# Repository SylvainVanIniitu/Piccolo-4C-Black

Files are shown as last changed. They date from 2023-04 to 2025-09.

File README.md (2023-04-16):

# PiccoloBlack
MIDI Stochastic Sequencer

Project of a stochastic MIDI sequencer developped since a few years (2016) in solo
I decided in 2023 to make its code and the schematics public and open to modifications by others

Piccolo is a polyrythmic errorist and stochastic MIDI sequencer, slightly verging towards a proto-programmable interpreter, very apt to generative and process-based music.the current version is based on the Teensy 4.1 architecture and MIDI protocol.    The previous versions  were relying on Teensy 3.5 and earlier ATmega2560.   The step to Teensy3.5 had provided 10x more precision in time, and 10x more memory.   the best place to see some movies of the action of the current prototypes is on my fb page : https://www.facebook.com/Piccolo-MIDI-sequencer-230847087794581/ 

i also compiled a few videos here : https://www.youtube.com/watch?v=yQdNbUFVs8c

several records have been released as Sylvain van iniitu or 4LLP4 CH1N0, using Piccolo as its main core

the current software version running the sequencer, and fully written in C, features :

MIDI in
MIDI out
OLED screen ( 4 lines of 20 characters ), in place of LCD screen
tap tempo ( different styles )
4 time-independent layers
64 layer memories ( to store layers and load then when necessary )
Unlimited duration loops ( unless you consider a maximum of 4 years as a limitation.. ), that can be independent.   Precision of 1 msec.  full 16 Channel capacity ( 16 channel can be used on each 4 layers )
Unlimited notes by layer ( up till the time the memory is full… we haven’t got there yet when playing )
more than 100 matrix transformations of the sequences ( delay, variable delay, transposition, harmonization, modulation, tonulation, reverse, inverse, simplification, etc... ) - most of it is crazy stuff, you'll just need to dive in the manual to get a clue
modulation of the layers by sequences : useful for (ir)regular transpositions, by note or by layer, modification of velocity, modification of length of note, etc.
possibility to program regular events, launching a transformation, either in absolute time, or after a certain repetition of one (or several) layers
sending CC to any channel, either time-based ( ex. modifying the length of a reverb every 30 sec ), or by note ( modifying it every 5 notes )
possibility to save and load layers as .txt files on SD cards. you can simply edit those .txt files on any text editor on any platform
reading .MIDI files on the SD card ; possibility to glitch those at core level
USB cable alimentation - does not require a computer to work
non-destructive and non-permanent delays, under various forms : regular delay, quad delay ( adapted from Tambour ), fractal delay ( adapted from Dende )
step sequencer : material 4 steps, but virtual from 2 to 127 steps ; you can program it with any note from any channel

Big thanks to : Ikue Mori, Steve Reich, Two Lone Swordsmen, Christian Wolff, Seth Horvitz (Sutekh), Phillus, Burnt Friedman, Cylob and Actress for most inspiration on building this thing.

Please send me the music you make with this sequencer !

If you make a short run of them, please send me one !

If you want to support, please buy my music at bandcamp E42.A8 : https://e42a8.bandcamp.com 

and if you like it : buy some more at https://stilll-off.bandcamp.com/album/sylvain-van-iniitu-plays-django-reinhardt 

or http://tanukirecords.bandcamp.com/album/vulgar-display-of-debug-vol-3-thrift-thrift-horatio

and yes, invite me for a workshop somewhere, and let me play a concert in your city ! 

P x L x U x R

sylvain van iniitu

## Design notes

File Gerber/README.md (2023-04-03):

BEWARE
there is still one flaw in these gerber files :
you'll need to attach a jumpwire from (-) to the mass in the PCB
please use the kiCad files named 14juillet to generate new Gerber files
i'll update ASAP

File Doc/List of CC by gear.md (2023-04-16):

COLECTED LIST of CC commands for useful gear ; please feel free to add some

// TX81Z

// Nord Drum 2

// Micro Sampler KORG

// Nord Lead 2

// Electribe mk2 

// Sherman

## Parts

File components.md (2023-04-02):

i will keep here a simple list of the components for the project, and a quick link on where to buy them
i mostly used Reichelt.de and Mouser.com until now, but i'll let it open for anyone who wants to contribute
i still need to indicated how many of each you'll need... 

let's start, with the obvious : 
* Teensy 4.1          https://www.pjrc.com/store/teensy41.html 
i used the normal version, but the NE should do fine as well

* Pushbuttons : Keylock Switches PB SWITCH SPST 
https://www.mouser.be/ProductDetail/CK/KS11R23CQD 
https://www.mouser.be/ProductDetail/CK/KS11R21CQD 
https://www.mouser.be/ProductDetail/CK/KS11R22CQD 

* DMX in : XLR connector
https://www.mouser.be/ProductDetail/Neutrik/NC3FBH2 

* MIDI connectors :
https://www.reichelt.de/be/en/din-socket-5-pin-semi-circular-printed-version-mabp-5s-p11178.html 

* Rectifier diode
https://www.reichelt.de/be/en/rectifier-diode-do35-100-v-0-2-a-1n-914-p1763.html 

* 6N138 optocoupler : necessary for MIDI in
https://www.reichelt.de/be/en/optocoupler-6n-138-p2859.html 

* MAX 485 CPA RS485/422 transceiver, DIP-8 
https://www.reichelt.de/be/en/rs485-422-transceiver-dip-8-max-485-cpa-p39599.html

* Rotary encoder with pushbutton 
https://www.reichelt.de/be/en/alps-stec12e-rotary-pulse-encoder-24-24-vert-w-pb-stec12e08-p73923.html 
* idem without pushbutton 
https://www.reichelt.de/be/en/alps-stec12e-rotary-pulse-encoder-24-24-vert-w-o-pb-stec12e07-p73922.html 

* OLED Screen : 
 /www.nhdforum.newhavendisplay.com/index.php?topic=914.0
https://www.mouser.be/ProductDetail/Newhaven-Display/NHD-0420CW-AY3 
i wrote a detailed post on wiring this one, here : 
https://forum.pjrc.com/threads/65710-teensy-4-1-OLED-4x20-NHD-0420CW-AY3 

* stuff to mount the whole ( legs, spacers, screws, etc )
https://www.reichelt.de/be/en/spacers-metal-6-edge-m4-5-mm-vt-da4-5mm-p231472.html 
https://www.reichelt.de/be/en/spacers-metal-6-edge-m3-5-mm-vt-da-5mm-p231465.html

* slider ( developpment not completely finished on this, though ) 
https://www.reichelt.de/be/en/alps-high-quality-sliding-potentiometer-linear-stereo-10k-rs60n12-lin10k-p73870.html  
+ fader button 
https://www.reichelt.de/be/en/fader-knob-for-rs60112-bl-knopf-4x1-2sw-p73945.html

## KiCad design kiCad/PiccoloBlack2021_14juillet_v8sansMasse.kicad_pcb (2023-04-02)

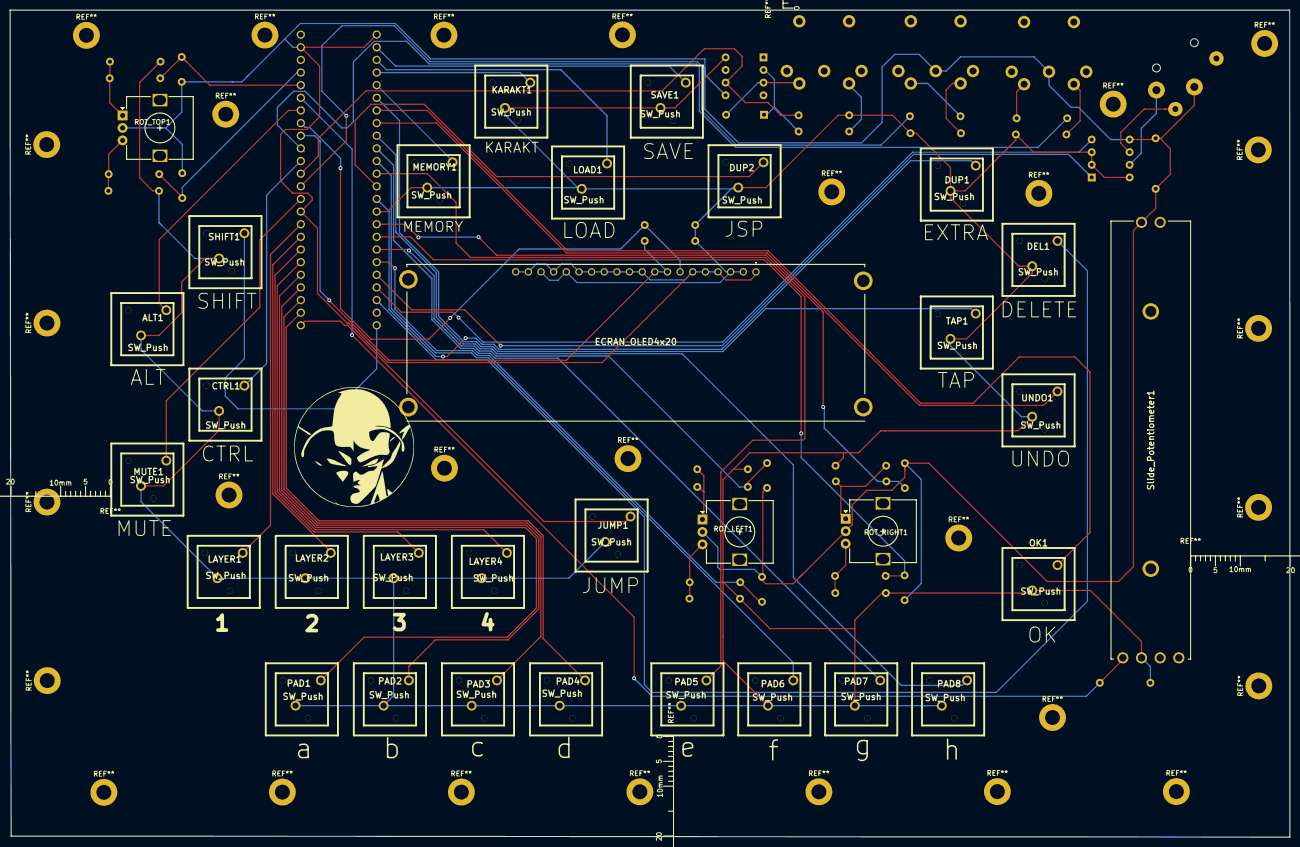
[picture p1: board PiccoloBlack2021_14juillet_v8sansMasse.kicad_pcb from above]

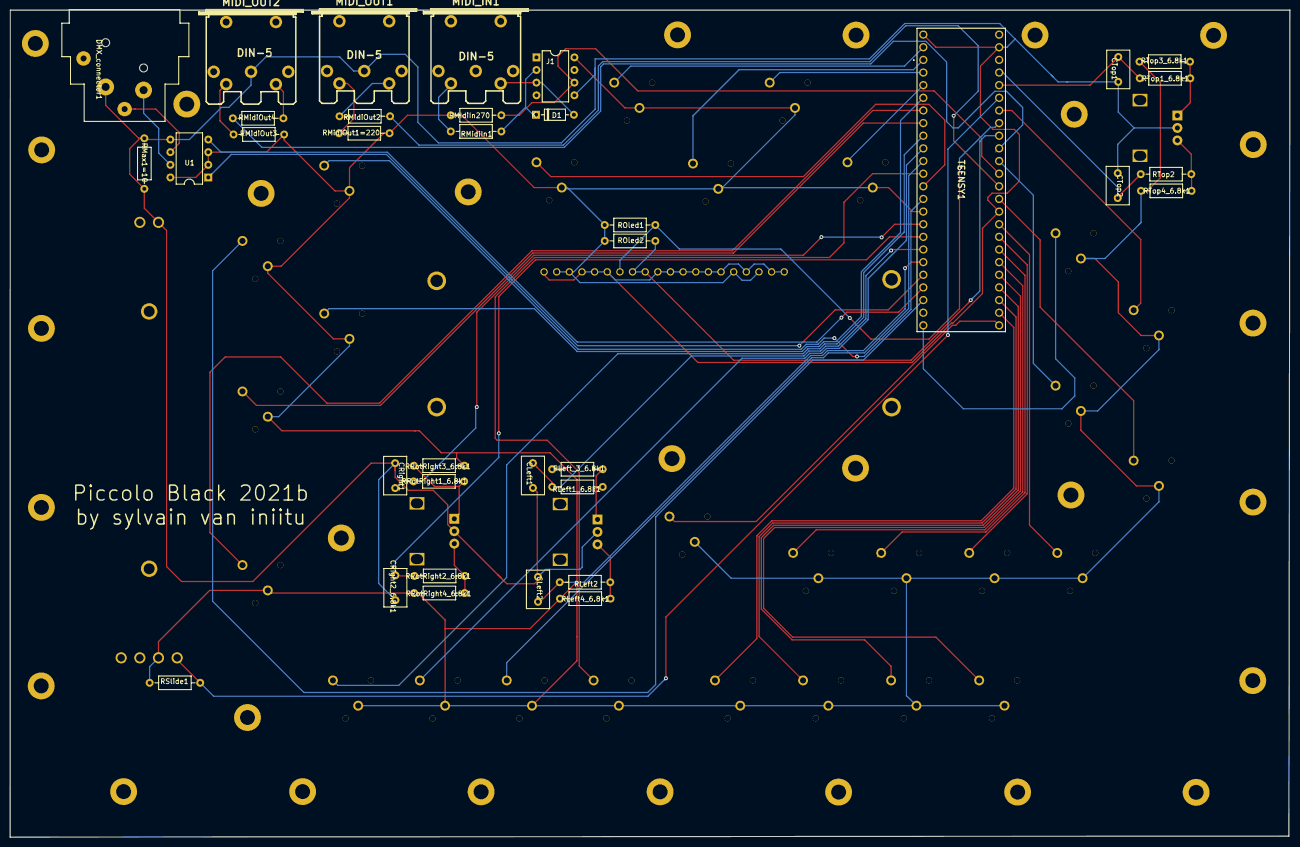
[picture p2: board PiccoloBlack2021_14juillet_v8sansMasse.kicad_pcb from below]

Board: 2 copper layers, 257.1 x 166.2 mm, 68 parts (36 on the bottom side), 58 nets.

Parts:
ALT1: SW_Push; PCB_PUSH2
CLeft1, CLeft2: C 0.01u = 103; C_Disc_D7.5mm_W4.4mm_P5.00mm
CRight1, CRight2_6.8k1: C 0.01u = 103; C_Disc_D7.5mm_W4.4mm_P5.00mm
CTRL1: SW_Push; PCB_PUSH2
CTop1, CTop2: C 0.01u = 103; C_Disc_D7.5mm_W4.4mm_P5.00mm
D1: 1N914; D_DO-35_SOD27_P7.62mm_Horizontal
DEL1: SW_Push; PCB_PUSH2
DMX_connector1: NC3FBH2; Jack_XLR_Neutrik_NC3FBH2_Horizontal
DUP1, DUP2: SW_Push; PCB_PUSH2
ECRAN_OLED4x20: NHD-0420CW-AW3; NHD0420CWAW3
J1: Conn_02x04_Counter_Clockwise; DIP-8_W7.62mm
JUMP1: SW_Push; PCB_PUSH2
KARAKT1: SW_Push; PCB_PUSH2
LAYER1, LAYER2, LAYER3, LAYER4: SW_Push; PCB_PUSH2
LOAD1: SW_Push; PCB_PUSH2
MEMORY1: SW_Push; PCB_PUSH2
MIDI_IN1: DIN-5; din-5
MIDI_OUT1, MIDI_OUT2: DIN-5; din-5
MUTE1: SW_Push; PCB_PUSH2
OK1: SW_Push; PCB_PUSH2
PAD1, PAD2, PAD3, PAD4, PAD5, PAD6, PAD7, PAD8: SW_Push; PCB_PUSH2
RLeft1_6.8k1, RLeft2, RLeft4_6.8k1: _6.8k; R_Axial_DIN0207_L6.3mm_D2.5mm_P10.16mm_Horizontal
RLeft_3_6.8k1: _6.8k; R_Axial_DIN0207_L6.3mm_D2.5mm_P10.16mm_Horizontal
RMIdiIn270: 270; R_Axial_DIN0207_L6.3mm_D2.5mm_P10.16mm_Horizontal
RMax1=10: R 10; R_Axial_DIN0207_L6.3mm_D2.5mm_P10.16mm_Horizontal
RMidiIn1: 220; R_Axial_DIN0207_L6.3mm_D2.5mm_P10.16mm_Horizontal
RMidiOut1=220, RMidiOut2, RMidiOut3, RMidiOut4: 220; R_Axial_DIN0207_L6.3mm_D2.5mm_P10.16mm_Horizontal
ROT_LEFT1: Rotary_Encoder; RotaryEncoder_Alps_EC12E_Vertical_H20mm
ROT_RIGHT1: Rotary_Encoder; RotaryEncoder_Alps_EC12E_Vertical_H20mm
ROT_TOP1: Rotary_Encoder; RotaryEncoder_Alps_EC12E_Vertical_H20mm
ROled1, ROled2: 6,8k; R_Axial_DIN0207_L6.3mm_D2.5mm_P10.16mm_Horizontal
RRotRight1_6.8k1: 6.8k; R_Axial_DIN0207_L6.3mm_D2.5mm_P10.16mm_Horizontal
RRotRight2_6.8k1, RRotRight3_6.8k1, RRotRight4_6.8k1: _6.8k; R_Axial_DIN0207_L6.3mm_D2.5mm_P10.16mm_Horizontal
RSlide1: 3,3k; R_Axial_DIN0207_L6.3mm_D2.5mm_P10.16mm_Horizontal
RTop1_6.8k1, RTop2, RTop3_6.8k1, RTop4_6.8k1: _6.8k; R_Axial_DIN0207_L6.3mm_D2.5mm_P10.16mm_Horizontal
SAVE1: SW_Push; PCB_PUSH2
SHIFT1: SW_Push; PCB_PUSH2
Slide_Potentiometer1: RS60N1219A04
TAP1: SW_Push; PCB_PUSH2
TEENSY1: TEENSY_4.1; TEENSY41sans_trous_du_milieux
U1: MAX485E; DIP-8_W7.62mm
UNDO1: SW_Push; PCB_PUSH2

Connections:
GND: CLeft1.1, CLeft2.1, CRight1.1, CRight2_6.8k1.1, CTop1.1, CTop2.1, DMX_connector1.1, ECRAN_OLED4x20.1, ECRAN_OLED4x20.4, ECRAN_OLED4x20.5, ECRAN_OLED4x20.6, ECRAN_OLED4x20.10, ECRAN_OLED4x20.11, ECRAN_OLED4x20.12, ECRAN_OLED4x20.13, ECRAN_OLED4x20.14, ECRAN_OLED4x20.15, ECRAN_OLED4x20.17, ECRAN_OLED4x20.19, ECRAN_OLED4x20.20, J1.5, MIDI_OUT1.2, MIDI_OUT2.2, RMax1=10.1, RMax1=10.2, ROT_LEFT1.C, ROT_RIGHT1.C, ROT_TOP1.C, Slide_Potentiometer1.5, TEENSY1.G1, TEENSY1.G2, TEENSY1.G3, U1.5
unnamed: ALT1.1, TEENSY1.20
unnamed: ALT1.2, CTRL1.2, DEL1.2, DUP1.2, DUP2.2, ECRAN_OLED4x20.2, ECRAN_OLED4x20.3, ECRAN_OLED4x20.16, ECRAN_OLED4x20.18, J1.8, JUMP1.2, KARAKT1.2, LAYER1.2, LAYER2.2, LAYER3.2, LAYER4.2, LOAD1.2, MEMORY1.2, MUTE1.2, OK1.2, PAD1.2, PAD2.2, PAD3.2, PAD4.2, PAD5.2, PAD6.2, PAD7.2, PAD8.2, RLeft4_6.8k1.2, RLeft_3_6.8k1.1, RMIdiIn270.2, RMidiOut1=220.1, RMidiOut3.1, ROled1.1, ROled2.2, RRotRight3_6.8k1.1, RRotRight4_6.8k1.2, RSlide1.1, RTop3_6.8k1.1, RTop4_6.8k1.2, SAVE1.2, SHIFT1.2, Slide_Potentiometer1.1, TAP1.2, TEENSY1.42, U1.2, U1.3, U1.8, UNDO1.2
unnamed: CLeft1.2, RLeft1_6.8k1.2, TEENSY1.26
unnamed: CLeft2.2, RLeft2.2, TEENSY1.27
unnamed: CRight1.2, RRotRight1_6.8k1.2, TEENSY1.24
unnamed: CRight2_6.8k1.2, RRotRight2_6.8k1.2, TEENSY1.25
unnamed: CTRL1.1, TEENSY1.16
unnamed: CTop1.2, RTop1_6.8k1.2, TEENSY1.22
unnamed: CTop2.2, RTop2.2, TEENSY1.23
unnamed: D1.1, J1.2, RMidiIn1.1
unnamed: D1.2, J1.3, MIDI_IN1.5
unnamed: DEL1.1, TEENSY1.30
unnamed: DMX_connector1.2, U1.7
unnamed: DMX_connector1.3, U1.6
unnamed: DUP1.1, TEENSY1.12
unnamed: DUP2.1, TEENSY1.11
unnamed: ECRAN_OLED4x20.7, ROled1.2, TEENSY1.19
unnamed: ECRAN_OLED4x20.8, ECRAN_OLED4x20.9, ROled2.1, TEENSY1.18
unnamed: J1.6, RMIdiIn270.1, TEENSY1.15
unnamed: JUMP1.1, TEENSY1.33
unnamed: KARAKT1.1, TEENSY1.2
unnamed: LAYER1.1, TEENSY1.41
unnamed: LAYER2.1, TEENSY1.40
unnamed: LAYER3.1, TEENSY1.39
unnamed: LAYER4.1, TEENSY1.38
unnamed: LOAD1.1, TEENSY1.1
unnamed: MEMORY1.1, TEENSY1.3
unnamed: MIDI_IN1.4, RMidiIn1.2
unnamed: MIDI_OUT1.4, RMidiOut1=220.2
unnamed: MIDI_OUT1.5, RMidiOut2.2
unnamed: MIDI_OUT2.4, RMidiOut3.2
unnamed: MIDI_OUT2.5, RMidiOut4.2
unnamed: MUTE1.1, TEENSY1.13
unnamed: OK1.1, TEENSY1.5
unnamed: PAD1.1, TEENSY1.37
unnamed: PAD2.1, TEENSY1.36
unnamed: PAD3.1, TEENSY1.35
unnamed: PAD4.1, TEENSY1.34
unnamed: PAD5.1, TEENSY1.10
unnamed: PAD6.1, TEENSY1.9
unnamed: PAD7.1, TEENSY1.8
unnamed: PAD8.1, TEENSY1.7
unnamed: RLeft1_6.8k1.1, RLeft_3_6.8k1.2, ROT_LEFT1.A
unnamed: RLeft2.1, RLeft4_6.8k1.1, ROT_LEFT1.B
unnamed: RMidiOut2.1, TEENSY1.14
unnamed: RMidiOut4.1, TEENSY1.17
unnamed: ROT_RIGHT1.A, RRotRight1_6.8k1.1, RRotRight3_6.8k1.2
unnamed: ROT_RIGHT1.B, RRotRight2_6.8k1.1, RRotRight4_6.8k1.1
unnamed: ROT_TOP1.A, RTop1_6.8k1.1, RTop3_6.8k1.2
unnamed: ROT_TOP1.B, RTop2.1, RTop4_6.8k1.1
unnamed: RSlide1.2, Slide_Potentiometer1.3, TEENSY1.21
unnamed: SAVE1.1, TEENSY1.57
unnamed: SHIFT1.1, TEENSY1.32
unnamed: TAP1.1, TEENSY1.4
unnamed: TEENSY1.6, UNDO1.1
unnamed: TEENSY1.28, U1.1
unnamed: TEENSY1.29, U1.4

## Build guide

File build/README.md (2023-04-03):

this folder contains one .HEX file that works as one of the latest tested software
you can upload this directly to Piccolo using the Teensy loader if you dont want to compile all the files yourself

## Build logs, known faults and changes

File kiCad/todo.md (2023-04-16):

missing prints on the schematics for 
* OLED-0420CW-AW3
* TEENSY_4.1
* DMX NC3FBH2 

refaire un plan avec Zone de Masse

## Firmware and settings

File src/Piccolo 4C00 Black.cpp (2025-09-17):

/*

here

PPPPPPPPPPPPPPPPP     iiii                                                           lllllll                              444444444
P::::::::::::::::P   i::::i                                                          l:::::l                             4::::::::4
P::::::PPPPPP:::::P   iiii                                                           l:::::l                            4:::::::::4
PP:::::P     P:::::P                                                                 l:::::l                           4::::44::::4
  P::::P     P:::::Piiiiiii     cccccccccccccccc    cccccccccccccccc   ooooooooooo    l::::l    ooooooooooo           4::::4 4::::4      cccccccccccccccc
  P::::P     P:::::Pi:::::i   cc:::::::::::::::c  cc:::::::::::::::c oo:::::::::::oo  l::::l  oo:::::::::::oo        4::::4  4::::4    cc:::::::::::::::c
  P::::PPPPPP:::::P  i::::i  c:::::::::::::::::c c:::::::::::::::::co:::::::::::::::o l::::l o:::::::::::::::o      4::::4   4::::4   c:::::::::::::::::c
  P:::::::::::::PP   i::::i c:::::::cccccc:::::cc:::::::cccccc:::::co:::::ooooo:::::o l::::l o:::::ooooo:::::o     4::::444444::::444c:::::::cccccc:::::c
  P::::PPPPPPPPP     i::::i c::::::c     cccccccc::::::c     ccccccco::::o     o::::o l::::l o::::o     o::::o     4::::::::::::::::4c::::::c     ccccccc
  P::::P             i::::i c:::::c             c:::::c             o::::o     o::::o l::::l o::::o     o::::o     4444444444:::::444c:::::c
  P::::P             i::::i c:::::c             c:::::c             o::::o     o::::o l::::l o::::o     o::::o               4::::4  c:::::c
  P::::P             i::::i c::::::c     cccccccc::::::c     ccccccco::::o     o::::o l::::l o::::o     o::::o               4::::4  c::::::c     ccccccc
PP::::::PP          i::::::ic:::::::cccccc:::::cc:::::::cccccc:::::co:::::ooooo:::::ol::::::lo:::::ooooo:::::o               4::::4  c:::::::cccccc:::::c
P::::::::P          i::::::i c:::::::::::::::::c c:::::::::::::::::co:::::::::::::::ol::::::lo:::::::::::::::o             44::::::44 c:::::::::::::::::c
P::::::::P          i::::::i  cc:::::::::::::::c  cc:::::::::::::::c oo:::::::::::oo l::::::l oo:::::::::::oo              4::::::::4  cc:::::::::::::::c
PPPPPPPPPP          iiiiiiii    cccccccccccccccc    cccccccccccccccc   ooooooooooo   llllllll   ooooooooooo                4444444444    cccccccccccccccc

2016-2025 sylvain van iniitu - some rights reserved -
This program is free software; you can redistribute it and/or
modify it under the terms of the Creative Commons 4.0 CC BY-NC-SA Licence

www.iniitu.net
you can support my music on Bandcamp > https://e42a8.bandcamp.com 
if you would like to buy a PCB get in touch

*/

// TODO

// avant Version RESIDENZ
// J'ai sacrifié GetNameTest pour Comb2 ! il faut restaurer ça pour Teensy !

// version qui effectue un pas en arrière concernant le CCMod
// alors que j'avais développé une version avec pointeurs, je retourne ici vers un array

// la valeur réelle est affichée en softwareValueEncoderRight
// celle ci est transmise à la transformation
// pour le random de Event, il faudra prévoir qu'il balance entre min et max de la transformation prévue
// vérifier l'affichage de ligne2 dans trasnformation 134 : choix de valeur min et valeur max de Event Transfo

// QUAND NOUVELLE VARIABLE INFLUENCANT LE JEU ET DEVANT ETRE SAUVEE SOUS KARAKT
// AJOUTER AU SAVE
// AJOUTER AU LOAD ( à partir de la ligne précédent )
// AJOUTER AU SAVE TO MEM
// AJOUTE AU LOAD FROM MEM

// 1 -
//  aller dans saveCurrentandMemKarakt() dans SaveLoadLocal.h
//  on rajoute en bas de cette fonction des _printToKarakt avec des chiffres consécutifs, ainsi que le nom de variable et description
//  faire un compile pour vérifier que OK

// 2
//  un peu plus bas, dans le même fichier, même fonction recopier les nouvelles lignes et modifier en fromKMem_int_printToKarakt
//  re-compiler

// 3
//  aller dans la fonction loadLocal2, même fichier
//  ajouters les nouvelles lignes et modifier en    int_loadFromKarakt(128, &keepStepzBUG );
//  re-compiler

// 5
//  recopier ces mêmes lignes EXACTEMENT sans rien modifer dans la fonction loadKarakt_from_KMem
//  re-compiler

// 4
//  aller ensuite dans le fichier karaktPile.h
//  trouver la fonction saveKarakt_to_KMem
//  y recopier les mêmes lignes juste modifée et en changeant le début par econome_int_saveToKMem(place,
//  sans le &
//  re-compiler

// procédures standard

#include <Arduino.h>
#include <MIDI.h>
#include <Encoder.h>
#include <EEPROM.h>
#include <bounce.h>
#include <affichage_functions.h>
#include <TeensyDMX.h>

// BLACK05 tentative de réinstauration de microSD en s'inspirant de
// https://forum.pjrc.com/threads/66326-Interference-between-SDFat-SDIO-and-I2S-on-T4-1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

#include <Wire.h>
#include <SPI.h>
#include "SdFat.h"

#define FILE_TRANSFER_BUFFER_SIZE 64
#define N_BUFFERS_IN_FILE 100

// MicroSD vars : SD_FAT_TYPE == 3
SdFs SDcard; // sd
FsFile dir;
// FsFile file;

// FsFile Wave0; // File on microSD card
FsFile myFile;
byte fileTransferBuffer[FILE_TRANSFER_BUFFER_SIZE] = {0};
uint32_t playbackFilePos = 0;
bool ready = false; // SD busy flag

// https://github.com/greiman/SdFs/blob/master/examples/TeensySdioDemo/TeensySdioDemo.ino
// https://github.com/greiman/SdFs/blob/master/examples/OpenNext/OpenNext.ino

// SD_FAT_TYPE = 1 for FAT16/FAT32, 2 for exFAT, 3 for FAT16/FAT32 and exFAT.
#define SD_FAT_TYPE 3
/*
  Change the value of SD_CS_PIN if you are using SPI and
  your hardware does not use the default value, SS.  
  Common values are:
  Arduino Ethernet shield: pin 4
  Sparkfun SD shield: pin 8
  Adafruit SD shields and modules: pin 10
*/

// SDCARD_SS_PIN is defined for the built-in SD on some boards.
#ifndef SDCARD_SS_PIN
const uint8_t SD_CS_PIN = SS;
#else  // SDCARD_SS_PIN
// Assume built-in SD is used.
const uint8_t SD_CS_PIN = SDCARD_SS_PIN;
#endif // SDCARD_SS_PIN

// Try to select the best SD card configuration.
#if HAS_SDIO_CLASS
#define SD_CONFIG SdioConfig(FIFO_SDIO)
#elif ENABLE_DEDICATED_SPI
#define SD_CONFIG SdSpiConfig(SD_CS_PIN, DEDICATED_SPI)
#else // HAS_SDIO_CLASS
#define SD_CONFIG SdSpiConfig(SD_CS_PIN, SHARED_SPI)
#endif // HAS_SDIO_CLASS

/*
#if SD_FAT_TYPE == 1
SdFat sd;
File dir;
File file;
#elif SD_FAT_TYPE == 2
SdExFat sd;
ExFile dir;
ExFile file;
#elif SD_FAT_TYPE == 3
SdFs sd;
FsFile dir;
FsFile file;
#else // SD_FAT_TYPE
#error invalid SD_FAT_TYPE
#endif // SD_FAT_TYPE
*/

//------------------------------------------------------------------------------
// Store error strings in flash to save RAM.
#define error(s) SDcard.errorHalt(&Serial, F(s))
//------------------------------------------------------------------------------

// END

MIDI_CREATE_INSTANCE(HardwareSerial, Serial3, MIDI3);

// DEFINITION De TOUS LES PINS : une bonne habitude à prendre si on pense qu'on gardera pas toujours le même support

// DELETE
// MIDI IN et OUT
// int pinRx3 = 7;
// int pinTx3 = 8;

// CREATION DU TIMER F8
IntervalTimer myTimerF8;
// CREATION DU TIMER Screen
IntervalTimer myTimerScreen;
// CREATION DU TIMER Screen
IntervalTimer myTimerEncoder;

int SizeTransfo = 613 - 1; // 22C01 :) 6 mars 2022
// c'est ajusté dans l'initialisation avec le nombre de transformations existantes !
// dans la fc void initialisationsDiverses(void) 

long time2checkEncoder = 1000000; // soit 1 seconde ?
long time2updateScreen = 5000;

bool readyToUpdateEncoder = true;

// values RIGHT

int multiplyRatioRight = 5;
int oldHardwareRight = -1;
int oldHardwareEncoderRight = -1;
int differenceHardwareRight = 0;
int absolutedifferenceHardwareRight = 0;
int stepSizeRight = 1;
int gapOfStepsToAccelerateRight = 5; // modifie la rapidité à accélérer

long softwareValueEncoderRight = 0;
long oldSoftwareRight = -1;
long olderSoftwareEncoderRight = -1;
long differenceSoftwareRight = 0;
long absoluteDifferenceSoftwareRight = 0;
long minimumSoftwareValueEncoderRight = 0;
long maximumSoftwareValueEncoderRight = 10000;
bool loopingValueRight = false;

// values modulated modulated RIGHT

long softwareValueEncoderRightModulated[8] = {100, 100, 100, 100, 100, 100, 0, 100}; //BLACK08
//
long oldSoftwareRightModulated[8] = {-1, -1, -1, -1, -1, -1, -1, -1};
long olderSoftwareEncoderRightModulated[8] = {-1, -1, -1, -1, -1, -1, -1, -1};
long differenceSoftwareRightModulated[8] = {0};
long absoluteDifferenceSoftwareRightModulated[8] = {0};
long minimumSoftwareValueEncoderRightModulated[8] = {0};
long maximumSoftwareValueEncoderRightModulated[8] = {10000, 10000, 10000, 10000, 10000, 10000, 10000, 10000};
bool loopingValueRightModulated[8] = {false, false, false, false, false, false, false, false};

// values LEFT

int multiplyRatioLeft = 1; // çàd pas d'accélération
int oldHardwareLeft = 0;
int oldHardwareEncoderLeft = 0;
int differenceHardwareLeft = 0;
int absolutedifferenceHardwareLeft = 0;
int stepSizeLeft = 1;
int gapOfStepsToAccelerateLeft = 10;
long softwareValueEncoderLeft = 0;
long oldSoftwareLeft = 0;
long olderSoftwareEncoderLeft = 0;
long differenceSoftwareLeft = 0;
long absoluteDifferenceSoftwareLeft = 0;
long minimumSoftwareValueEncoderLeft = 0;
long maximumSoftwareValueEncoderLeft = SizeTransfo - 1;
bool loopingValueLeft = true;

// values UP

int multiplyRatioUp = 0;
int oldHardwareUp = 0;
int oldHardwareEncoderUp = 0;
int differenceHardwareUp = 0;
int absolutedifferenceHardwareUp = 0;
int stepSizeUp = 1;
int gapOfStepsToAccelerateUp = 10;
long softwareValueEncoderUp = 0;
long oldSoftwareUp = 0;
long olderSoftwareEncoderUp = 0;
long differenceSoftwareUp = 0;
long absoluteDifferenceSoftwareUp = 0;
long minimumSoftwareValueEncoderUp = 0;
long maximumSoftwareValueEncoderUp = 8 ; // type de keyboards mode 
long loopingValueUp = true;

int measuredHighest = 800;
int measuredLowest = 100;

namespace teensydmx = ::qindesign::teensydmx;
teensydmx::Sender dmxTx{Serial7};

String display = "";

// DEFINITION DES PINS, ENCODERS et BOUTONS BLACK 03 - 2 juin 2021

// BOUTONS

const int pinButtonSave = 0;
const int pinButtonLoad = 1;
const int pinButtonKarakt = 2;
const int pinButtonMemory = 3;
const int pinButtonTap = 4;
const int pinButtonOK = 5;
const int pinButtonUndo = 6;
const int pinButtonPad8 = 7;

const int pinButtonPad7 = 8;
const int pinButtonPad6 = 9;
const int pinButtonPad5 = 10;
const int pinButtonJSP = 11;
const int pinButtonExtra = 12;
const int pinButtonMute = 13;

const int pinMidiOut1 = 14;   // TX3
const int pinMidiIn1 = 15;    // RX3
const int pinButtonCtrl = 16; // ATTENTION EST AUSSI RX4 ! voir si pose souci ou pas
const int pinMidiOut2 = 17;   // TX4
const int pinOled1 = 18;
const int pinOled2 = 19;
const int pinButtonAlt = 20;
const int pinSlidePotentiometer = 21;

// ENCODEURS ROTATIFS SIMPLES

const int pinRotaryUpA = 23; // ROTARY UP
const int pinRotaryUpB = 22;

const int pinRotaryRightA = 25; // ROTARY RIGHT
const int pinRotaryRightB = 24;

const int pinRotaryLeftA = 27; // ROTARY LEFT
const int pinRotaryLeftB = 26;

// BOUTONS LA SUITE

const int pinDMXin = 28;
const int pinDMXout = 29;

const int pinButtonDel = 30;
const int pinCTX3 = 31;
const int pinButtonShift = 32;
const int pinButtonJump = 33;
const int pinButtonPad4 = 34;
const int pinButtonPad3 = 35;
const int pinButtonPad2 = 36;
const int pinButtonPad1 = 37;
const int pinButtonLayer4 = 38;
const int pinButtonLayer3 = 39;
const int pinButtonLayer2 = 40;
const int pinButtonLayer1 = 41;

// const int pinButtonSave = 57;

Encoder rotKnobUp(pinRotaryUpA, pinRotaryUpB);
Encoder rotKnobLeft(pinRotaryLeftA, pinRotaryLeftB);
Encoder rotKnobRight(pinRotaryRightA, pinRotaryRightB);

// new names Black005 - 16juillet2021

Bounce myButtonSave(pinButtonSave, 10);
Bounce myButtonLoad(pinButtonLoad, 10);
Bounce myButtonKarakt(pinButtonKarakt, 10);
Bounce myButtonMemory(pinButtonMemory, 10);
Bounce myButtonTap(pinButtonTap, 10);
Bounce myButtonOK(pinButtonOK, 10);
Bounce myButtonUndo(pinButtonUndo, 10);
Bounce myButtonPad8(pinButtonPad8, 10);

Bounce myButtonPad7(pinButtonPad7, 10);
Bounce myButtonPad6(pinButtonPad6, 10);
Bounce myButtonPad5(pinButtonPad5, 10);
Bounce myButtonJSP(pinButtonJSP, 10);
Bounce myButtonExtra(pinButtonExtra, 10);
Bounce myButtonMute(pinButtonMute, 10);

Bounce myButtonCtrl(pinButtonCtrl, 10);
Bounce myButtonAlt(pinButtonAlt, 10);
Bounce myButtonDel(pinButtonDel, 10);
Bounce myButtonShift(pinButtonShift, 10);
Bounce myButtonJump(pinButtonJump, 10);
Bounce myButtonPad4(pinButtonPad4, 10);
Bounce myButtonPad3(pinButtonPad3, 10);
Bounce myButtonPad2(pinButtonPad2, 10);
Bounce myButtonPad1(pinButtonPad1, 10);
Bounce myButtonLayer4(pinButtonLayer4, 10);
Bounce myButtonLayer3(pinButtonLayer3, 10);
Bounce myButtonLayer2(pinButtonLayer2, 10);
Bounce myButtonLayer1(pinButtonLayer1, 10);

/// *****************

// procédures "maison"
//

void updateEncoder(void)
{
    readyToUpdateEncoder = true;
}

void addF8(void)
{
    readyToSendF8 = true;
}

void updateScreen(void)
{
    readyToUpdateScreen = true;
}

// OLD PICCOLO
// ENCODEURS ROTATIFS + PUSHBUTTON
//
// int pinRotaryEncoder1A = 30; // COARSE + FINE
// int pinRotaryEncoder1B = 29;
// int pinPushRE1 = 31;
byte readPinPushR1 = HIGH;

long lastPushREVel[4] = {0};
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
void loop()
{
    nowMicros = micros();
    nowMillis = nowMicros / 1000;

    // ***************************************************************************
    // LECTURE DES SENSEURS
    // ***************************************************************************

    // lecture encodeurs rotatifs

    //  myButtonOK.update();
    //  if (myButtonOK.risingEdge())
    {
        //  oledWriteStringAtXY("OK", 1, 0);
        //    printRot2("OK", 9, 400, 5);
        //  delay(5000);
    }

    // myButtonMemory.update();
    // if (myButtonMemory.risingEdge())
    {
        //        oledWriteStringAtXY("Memory", 1, 0);
        // printRot2("Memory", 9, 400, 5);
        // delay(5000);
    }

    myButtonSave.update();
    myButtonLoad.update();
    myButtonKarakt.update();
    myButtonMemory.update();
    myButtonTap.update();
    myButtonOK.update();
    myButtonUndo.update();
    myButtonPad8.update();

    myButtonPad7.update();
    myButtonPad6.update();
    myButtonPad5.update();
    myButtonJSP.update();
    myButtonExtra.update();
    myButtonMute.update();

    myButtonCtrl.update();
    myButtonAlt.update();
    myButtonDel.update();
    myButtonShift.update();
    myButtonJump.update();
    myButtonPad4.update();
    myButtonPad3.update();
    myButtonPad2.update();
    myButtonPad1.update();
    myButtonLayer4.update();
    myButtonLayer3.update();
    myButtonLayer2.update();
    myButtonLayer1.update();

    // Lecture RIGHT

    int32_t a = rotKnobRight.read() / 4;

    if (a != oldHardwareRight && synthesePressed == 0) // çàd pas de modulation
    {
        differenceHardwareRight = a - oldHardwareRight;

        softwareValueEncoderRight = softwareValueEncoderRight + differenceHardwareRight * stepSizeRight;

        if ((softwareValueEncoderRight < minimumSoftwareValueEncoderRight && loopingValueRight == false) || (softwareValueEncoderRight > maximumSoftwareValueEncoderRight && loopingValueRight == true))

        {
            softwareValueEncoderRight = minimumSoftwareValueEncoderRight;
            stepSizeRight = 1;
        }

        if ((softwareValueEncoderRight > maximumSoftwareValueEncoderRight && loopingValueRight == false) || (softwareValueEncoderRight < minimumSoftwareValueEncoderRight && loopingValueRight == true))

        {
            softwareValueEncoderRight = maximumSoftwareValueEncoderRight;
            stepSizeRight = 1;
        }

        oldHardwareRight = a;
        oldSoftwareRight = softwareValueEncoderRight;
    }

    // Lecture modulated RIGHT = BLACK08

    if (a != oldHardwareRight && synthesePressed == binCtrl) // çàd CTRL + encoder
    {
        differenceHardwareRight = a - oldHardwareRight;

        softwareValueEncoderRightModulated[6] = softwareValueEncoderRightModulated[6] + differenceHardwareRight * stepSizeRight;

        if ((softwareValueEncoderRightModulated[6] < minimumSoftwareValueEncoderRightModulated[6] && loopingValueRightModulated[6] == false) || (softwareValueEncoderRightModulated[6] > maximumSoftwareValueEncoderRightModulated[6] && loopingValueRightModulated[6] == true))
        {
            softwareValueEncoderRightModulated[6] = minimumSoftwareValueEncoderRightModulated[6];
            stepSizeRight = 1;
        }

        if ((softwareValueEncoderRightModulated[6] > maximumSoftwareValueEncoderRightModulated[6] && loopingValueRightModulated[6] == false) || (softwareValueEncoderRightModulated[6] < minimumSoftwareValueEncoderRightModulated[6] && loopingValueRightModulated[6] == true))
        {
            softwareValueEncoderRightModulated[6] = maximumSoftwareValueEncoderRightModulated[6];
            stepSizeRight = 1;
        }

        oldHardwareRight = a;
        oldSoftwareRightModulated[6] = softwareValueEncoderRightModulated[6];
    }

    if (a != oldHardwareRight && synthesePressed == binAlt) // çàd ALT + encoder
    {
        differenceHardwareRight = a - oldHardwareRight;

        softwareValueEncoderRightModulated[5] = softwareValueEncoderRightModulated[5] + differenceHardwareRight * stepSizeRight;

        if ((softwareValueEncoderRightModulated[5] < minimumSoftwareValueEncoderRightModulated[5] && loopingValueRightModulated[5] == false) || (softwareValueEncoderRightModulated[5] > maximumSoftwareValueEncoderRightModulated[5] && loopingValueRightModulated[5] == true))
        {
            softwareValueEncoderRightModulated[5] = minimumSoftwareValueEncoderRightModulated[5];
            stepSizeRight = 1;
        }

        if ((softwareValueEncoderRightModulated[5] > maximumSoftwareValueEncoderRightModulated[5] && loopingValueRightModulated[5] == false) || (softwareValueEncoderRightModulated[5] < minimumSoftwareValueEncoderRightModulated[5] && loopingValueRightModulated[5] == true))
        {
            softwareValueEncoderRightModulated[5] = maximumSoftwareValueEncoderRightModulated[5];
            stepSizeRight = 1;
        }

        oldHardwareRight = a;
        oldSoftwareRightModulated[5] = softwareValueEncoderRightModulated[5];
    }

    // BLACK09

    if (a != oldHardwareRight && synthesePressed == binShift ) // çàd Shift  + encoder
    // Va déterminer la page affichée
    {
        differenceHardwareRight = a - oldHardwareRight;

        softwareValueEncoderRightModulated[7] = softwareValueEncoderRightModulated[7] + differenceHardwareRight * stepSizeRight;

        if ((softwareValueEncoderRightModulated[7] < minimumSoftwareValueEncoderRightModulated[7] && loopingValueRightModulated[5] == false) || (softwareValueEncoderRightModulated[5] > maximumSoftwareValueEncoderRightModulated[5] && loopingValueRightModulated[5] == true))
        {
            softwareValueEncoderRightModulated[7] = minimumSoftwareValueEncoderRightModulated[7];
            stepSizeRight = 1;
        }

        if ((softwareValueEncoderRightModulated[7] > maximumSoftwareValueEncoderRightModulated[7] && loopingValueRightModulated[5] == false) || (softwareValueEncoderRightModulated[5] < minimumSoftwareValueEncoderRightModulated[5] && loopingValueRightModulated[5] == true))
        {
            softwareValueEncoderRightModulated[7] = maximumSoftwareValueEncoderRightModulated[7];
            stepSizeRight = 1;
        }

        oldHardwareRight = a;
        oldSoftwareRightModulated[7] = softwareValueEncoderRightModulated[7];

        pageEndUser = softwareValueEncoderRightModulated[7];
        currentPageStepz = pageEndUser;

        if (pageEndUser > numberMaxPageStepz)
        {
            currentPageStepz = numberMaxPageStepz;
            pageEndUser = currentPageStepz ;
            softwareValueEncoderRightModulated[7] = currentPageStepz ;
        }

        if (pageEndUser < 0)
        {
            currentPageStepz = 0;
            pageEndUser = currentPageStepz;
            softwareValueEncoderRightModulated[7] = currentPageStepz;
        }

    }

    // Lecture LEFT

    a = rotKnobLeft.read() / 4;

    if (a != oldHardwareLeft)
    {
        differenceHardwareLeft = a - oldHardwareLeft;

        softwareValueEncoderLeft = softwareValueEncoderLeft + differenceHardwareLeft * stepSizeLeft;

        // BLACK06 la plupart du temps, qd on bouge l'encodeur gauche
        // on change de transformation
        // et il faut donc modifier les min et max pour l'encodeur de droite

        minimumSoftwareValueEncoderRight = Transfo[softwareValueEncoderLeft][1];
        maximumSoftwareValueEncoderRight = Transfo[softwareValueEncoderLeft][2];

        // TODO BLACK08 ne faut-il pas ici rappeler l'ancienne valeur de Right ?

        if ((softwareValueEncoderLeft < minimumSoftwareValueEncoderLeft && loopingValueLeft == false) || (softwareValueEncoderLeft > maximumSoftwareValueEncoderLeft && loopingValueLeft == true))

        {
            softwareValueEncoderLeft = minimumSoftwareValueEncoderLeft;
            stepSizeLeft = 1;
        }

        if ((softwareValueEncoderLeft > maximumSoftwareValueEncoderLeft && loopingValueLeft == false) || (softwareValueEncoderLeft < minimumSoftwareValueEncoderLeft && loopingValueLeft == true))

        {
            softwareValueEncoderLeft = maximumSoftwareValueEncoderLeft;
            stepSizeLeft = 1;
        }

        oldHardwareLeft = a;
        oldSoftwareLeft = softwareValueEncoderLeft;
    }

    //   oledWriteStringAtXY(String(a) + " ", 7, 0);
    //   oledWriteStringAtXY(String(softwareValueEncoderLeft) + " ", 7, 1);

    // Lecture UP

    a = rotKnobUp.read() / 4;

    if (a != oldHardwareUp)
    {
        differenceHardwareUp = a - oldHardwareUp;

        softwareValueEncoderUp = softwareValueEncoderUp + differenceHardwareUp * stepSizeUp;

        if ((softwareValueEncoderUp < minimumSoftwareValueEncoderUp && loopingValueUp == false) || (softwareValueEncoderUp > maximumSoftwareValueEncoderUp && loopingValueUp == true))
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

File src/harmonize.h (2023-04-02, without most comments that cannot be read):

// TODO
// Clean par suppression
// Clean par fluctuation
// Clean par reproduction

// Passage d'une gamme à une autre

// PROTOTYPES
bool isNoteInScaleMode(int z,int gammeActuelle,long  potVal3) ;
bool isNoteInTriadNumber(int z,int triadNumber ) ;
String GiveNameOfNote ( int NNN ) ;
void simplePartialSortZeroNotesv2(int layer ) ;

// https://www.basicmusictheory.com/c-sharp-major-scale

/* Unfortunately, most C++ compilers do not have any means of expressing binary numbers directly in source code.

A few allow the prefix 0b followed by a series of 0 and 1 digits, e.g. 0b11 == 3.
The C++ compiler used by Arduino does not support this syntax. However, starting in Arduino 0007,
the constants B0 through B11111111 are defined for your convenience.
*/

// const int nbDeModesConnus = 14;
// const unsigned long Scale[nbDeModesConnus] = { 2741L, 1453L, 2477L, 2733L, 661L, 1193L, 1717L, 2773L, 1749L, 1459L, 1709L, 1451L, 1387L, 1365L  } ;
// 1C89 mis dans variables

/*
0 ScaleMajor =  2741L;

// ce chiffre se lit donc : ton, ton, demi-ton, ton, ton, ton, demi-ton
1 ScaleMinorNatural =  1453L;   // 010110101101  ; // ton, demi-ton, ton, ton, demi-ton, ton, ton
2 ScaleMinorHarmonic = 2477L;   //  100110101101  ; // ton, demi-ton, ton, ton, demi-ton, 1 ton et demi, demi-ton
3 ScaleMinorMelodic =  2733L;   // 101010101101  ; // ton, demi-ton, ton, ton, ton, ton, demi-ton
4 ScalePentatonicMajor =  661L;      // 001010010101  ; // ton, ton, ton et demi, ton, ton et demi
5 ScalePentatonicMinor =  1193L;      // 010010101001  ; // ton et demi, ton, ton, ton et demi, ton
6 Mixolydian
7 Lydian
8 Lydian Dominant
9 Phrygian Dominant
10 Dorian
11 Phrygian
12 Locrian
13 Hexa  = 1365L / 10101010101

Janvier 2019 :
je refais tout le processus pour vérification
1. nom du mode
2. représentation des places des notes : 1 = notes, 0 = pas de notes.   l'espace entre les 1 décrit donc ton et demi-ton
3. inversion gauche-droite
4. écriture en binaire
5. équivalent décimal

MAJOR
101011 010101
101010110101
2741 OK

MIXOLYDIAN
101011 010110
011010110101
1717

LYDIAN
101010 110101
101011010101
2773

LYDIAN DOMINANT
101010 110110
011011010101
1749

PHRYGIAN DOMINANT
110011 011010
010110110011
1459

NATURAL MINOR
101101 011010
010110101101
1453 OK

DORIAN
101101 010110
011010101101
1709

HARMONIC MINOR
101101 011001
100110101101
2477 OK

MELODIC MINOR
101101 010101
101010101101
2733 OK

PHRYGIAN
110101 011010
010110101011
1451

LOCRIAN
110101 101010
010101101011
1387

DODECA  // 2C28 
111111 111111
111111111111
4095 

*/


// int activeLayer = 1 ;

// inline void wait_on_enter()
// {
//     std::string dummy;
//     std::cout << std::endl << "Enter to continue..." << std::endl;
//     std::getline(std::cin, dummy);
//     cout << endl << endl ;
// }

/////////////////////////////////////////////////////////////////////////////////////
// PILE VERSION : faite et vérifiée
// 1C94
/////////////////////////////////////////////////////////////////////////////////////

void newHarmonize( byte layer, int gammeActuelle  , long potVal3  )
/** \brief fonction qui va faire rentrer une melodymatrix dans une gamme donnée ( gammeActuelle ) et un un mode donné ( potVal3 )
*
* \param gammeActuelle décrit la note de base de la gamme.  0=C 1=C# 2=D, etc
* \param potVal3 décrit le mode.  0=major, etc.
* \return
*
*/

{
   // for (int i = 0 ; i < nbLayer ; i ++ )
    {
        // if ( isLayerActive(i ) )
        int i = layer ; 
  
         {
          unsigned int taille = mesureTaillePileComplete(pInitial[i]);
        
            for ( unsigned int j  = 0 ; j  < taille ; j  ++ )
            {
                pileNote tempNote;
                tempNote = ZEROgetNoteFromPile(pInitial[i], j);
                
                if ( tempNote.note != 0 && ( tempNote.type == 0x90 || tempNote.type == 0x80 ) && pitchableChannel[tempNote.channel] == true && pitchableLayer[tempNote.layer] == true )
                {
                    // d'abord il faut réduire la melody(note) à une note

                    int rootnote =   tempNote.note  % 12 ; // k devient la note entre 0 (C) et 11 (B)



                    //
                    //                              while  ( isNoteInScaleMode(rootnote,gammeActuelle,potVal3) == false  )
                    //                              {
                    //
                    //                                    melodyMatrix[i][j][MMnote] = melodyMatrix[i][j][MMnote] + (rand () % 2) - (rand () % 2) ;
                    //                                    // va augmenter ou réduire le pitch jusqu'à ce que colle à la gamme.
                    //                                    rootnote =   melodyMatrix[i][j][MMnote] % 12 ; // rootnote devient la note entre 0 (C) et 11 (B)
                    //
                    //                              }


                    signed int ajoutPitch = 0 ;

                    ajoutPitch = (( rand () % 2 ) == 0 )?+1:-1 ;
                    // dans le premier cas on fera du plus 1, dans le second, du moins 1

                    while  ( isNoteInScaleMode(rootnote,gammeActuelle,potVal3) == false  )
                    {
                        tempNote.note = modifyPitchUniversal(tempNote,tempNote.note,ajoutPitch )  ;
                        // va augmenter ou réduire le pitch jusqu'à ce que colle à la gamme.
                        rootnote =   tempNote.note % 12 ; // rootnote devient la note entre 0 (C) et 11 (B)
                    }

                    ZEROSetNoteInPile(pInitial[i], j, tempNote);
                }
            }
        }
    }
}

float giveInclusion ( int gamme   , long mode   )
{
    int compteurIN = 0 ;
    int compteurTOT = 0 ;
    float resultat = 0.0 ;

    for (int i = 0 ; i < nbLayer ; i ++ )
    {
        if ( isLayerActive(i) )
        {

            unsigned int taille = mesureTaillePileComplete(pInitial[i]);
           
            for ( unsigned int j = 0 ; j < taille  ; j ++ )
            {

                pileNote tempNote;
                tempNote = ZEROgetNoteFromPile(pInitial[i], j);
               
                if ( tempNote.note != 0 )
                {


                    int rootnote = tempNote.note % 12; // k devient la note entre 0 (C) et 11 (B)




                    if  ( isNoteInScaleMode(rootnote, gamme , mode ) )
                    {
                        compteurIN++ ;
                    }
                    compteurTOT++ ;
                }
            }
        }
    }

    if ( compteurTOT != 0 )
    {
        // cout << compteurIN << " notes sur " << compteurTOT << " sont dans la gamme\n" ;
        resultat =   ( (float) compteurIN * 100.0 ) / (float) compteurTOT   ;
    }
    else
    {
        //  cout << compteurIN << " notes sont dans la gamme\n" ;
        resultat =   0;
    }

    return resultat ;
}
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

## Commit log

2023-03-25 changement de nom
2023-04-02 updating schematics kiCad gerber
    [PiccoloBlack2021_14juillet_v8sansMasse.kicad_pcb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]
2023-04-02 changing folder place for Gerber and kiCad
    [PiccoloBlack2021_14juillet_v8sansMasse.kicad_pcb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]
2023-04-03 Create README.md
    warning about gerber files
2023-04-16 Rename List of CC by gear to List of CC by gear.md
2023-04-16 working on kiCad update
2025-09-17 correction CH set SEQ
    [Piccolo 4C00 Black.cpp]
2025-09-17 fix set CH SEQ
    [Piccolo 4C00 Black.cpp]
